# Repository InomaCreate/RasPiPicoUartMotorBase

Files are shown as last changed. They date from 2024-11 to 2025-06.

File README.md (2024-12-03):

# 概要
raspiPICO+KITRONIK-5331を使ったDCモーター制御車両ベースです。  
RasPiPicoUartMotorBase_image4

UART通信を使い、モーター駆動指示、モーター回転数を取得します。
RasPiPicoUartMotorBase_image3

## UART通信仕様
RasPiPicoUartMotorBaseとマイコン等の制御用ボードをUARTで接続し、以下のコマンドをUARTで通知することでDCモーターを駆動させることが可能です。  
また、モーターの回転数（rpm)の情報をUARTで受信することができます。

### UARTコマンド
| UARTコマンド(制御ボード→RasPiPicoUartMotorBase) | 説明 |
|:---|:---:|
|start${"v_r": 右モーター速度指示値, "v_l":左モーター速度指示値} |モーター駆動指示 |  
|emergency_stop|モーター停止 |

※速度指示値は0〜100 ※終端に改行コードCRLF(\r\n)を入れること

| UART応答(制御ボード←RasPiPicoUartMotorBase) | 説明 |
|:---|:---:|
|{"rpm_l":左モーター回転数(rpm),"rpm_r":右モーター回転数(rpm)} |モーター回転数応答 |  

## 準備
### 必要なもの
- Raspberry Pi Pico
- Raspberry Pi Pico用Kitronikモータードライバーボード(KITRONIK-5331)
- エンコーダ付きDCモーター×2個
  - 動作実績：DC 12v モーター エンコーダ付き ギアモーター マウントブラケット付き 65mm(130rpm)
- モーター駆動用バッテリ(モーター電圧に応じて準備）
  
### ソフトウェア
※Raspberry Pi Pico開発環境はThonnyを使用
https://thonny.org/

1. Micro Pythonのファームウェアをセットアップしてください。  
以下サイト参照。  
https://www.marutsu.co.jp/pc/static/large_order/zep/m-z-picoled-da1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  

3. Kitronik用のドライバー(PicoMotorDriver.py)をRaspberry Pi Picoに保存します。    
以下参照。  
https://github.com/KitronikLtd/Kitronik-Pico-Motor-Driver-Board-MicroPython

4. RasPiPicoSource内にあるmain.pyをRaspberry Pi Picoに保存します。  
https://github.com/InomaCreate/RasPiPicoUartMotorBase/blob/main/RasPiPicoSource/main.py

### ハードウェア
1. raspiPICO+KITRONIK-5331を接続し、UART用線を出します。（要ハンダ付け）  
UART1 TX:GPIO4(PIN6), UART1 RX:GPIO5(PIN7), GND(PIN8)から線を出します。  

2. 以下のようにDCモーターと接続します。  
RasPiPicoUartMotorBase_image2new

実際の配線写真↓  
RasPiPicoUartMotorBase_image1

## サンプルプログラム
### 動作実績：
- Raspberry Pi 5（Ubuntu24.04)  
以下、Raspberry Pi 5（Ubuntu24.04)を使ったサンプルプログラムのセットアップ、実行方法を記載します。  

### セットアップ：
1. Raspberry Pi5のUART通信を有効にする  
   1-1. /boot/firmware/config.txtを編集し、以下を追加します。  
   ```enable_uart=1```  
   ```dtoverlay=uart0```  

   1-2. Raspberry Pi5を再起動します  
   ```sudo reboot```
    
   1-3. 再起動後、以下コマンドでuartが有効になっているか確認します。  
   ```sudo dmesg | grep ttyAMA```  
   ttyAMA0が有効になっている場合、以下のピンがUART信号のピンです。  
   ttyAMA0・・・PIN8：GPIO14（TxD）/ PIN10：GPIO15(RxD)  

   1-4. RasPiPicoUartMotorBaseのUART線をRaspberry Pi5のUARTピンと接続します。
   ![RasPiPicoUartMotorBase_image5](https://github.com/user-attachments/assets/a5f7ab8e-4351-4c18-8c67-189dea765469)

3. Raspberry Pi5に必要なパッケージのインストール  
以下のコマンドで、サンプルプログラムを実行するために必要なパッケージをインストールします  
```sudo apt update```  
```sudo apt install libncurses5-dev libncursesw5-dev```  
```pip3 install pyserial```  

### 実行方法：
セットアップしたRaspberry Piでサンプルプログラムを動かします。  
#### モーター駆動用サンプルプログラム
以下スクリプトを実行すると、モーター駆動用のサンプルプログラムが起動します。  
キーを通知すると、前進、後進、モーター速度変更などを行います。（以下表参照）  
```python3 sample_motor_send.py```  

| キー | 動作 |
|:---|:---:|
| i | 前進 |
| k | 後進 |
| s | 右モーター速度UP(+5) |
| a | 左モーター速度UP(+5) |
| x | 右モーター速度DOWN(-5) |
| z | 左モーター速度DOWN(-5) |
| e | モーター停止 |
| q | プログラム終了 |

#### モーター回転数受信サンプルプログラム
以下スクリプトを実行すると、モーター回転数受信のサンプルプログラムが起動します。  
```python3 sample_rcv_rpm.py``` 

## 3Dデータ
3Dデータ(stlファイル）もGitHubにUPしました。必要に応じて3Dプリンターで印刷してご使用ください。  
[https://github.com/InomaCreate/RasPiPicoUartMotorBase/tree/main/3D-data](https://github.com/InomaCreate/RasPiPicoUartMotorBase/blob/main/3D-data/RasPiPicoUartMotorBase_body-Body.stl)

以下のように、Raspberry Pi Picoや電池ボックス、モーター、キャスターを取り付けれるようにしております。
![github_image-06](https://github.com/user-attachments/assets/e641a84a-373e-4542-b344-a977cca06a89)
キャスターは、ホームセンターで買った直径38mmのものです。  
![github_image-07](https://github.com/user-attachments/assets/fa3f5e5d-8827-4ea0-8a7e-6b4a5467271e)

モーターのマウントは、「DC 12v モーター エンコーダ付き ギアモーター マウントブラケット付き 65mm(130rpm)」に付属されていたマウントブランケットをそのまま使用しています。  
![github_image-08](https://github.com/user-attachments/assets/a013b6a9-5359-4d2f-8b34-fa3b3e6589ed)

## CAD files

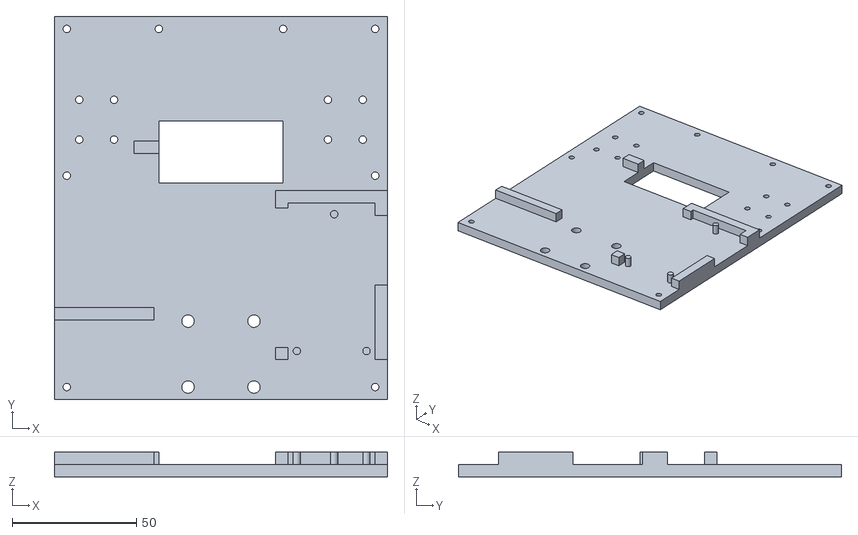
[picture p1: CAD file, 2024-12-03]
3D-data/RasPiPicoUartMotorBase_body-Body.stl
134.0 x 154.0 x 10.0

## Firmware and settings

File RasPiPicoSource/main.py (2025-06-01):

from machine import Pin, I2C, UART
import time
import json
import PicoMotorDriver


import utime
import math
import _thread
import uasyncio as asyncio

#GP２５のLEDを出力ピンとして設定 
led = machine.Pin(25, machine.Pin.OUT)

#出力ピンのスイッチをオン（１）
led.value(1)
 
#指定の秒数待機（５）
utime.sleep(5)
 
#出力ピンのスイッチをオフ（０）
led.value(0)

#GPIOピン番号(左モーター)
LEFT_ENC_A = 0
LEFT_ENC_B = 1

#GPIOピン番号(右モーター)
RIGHT_ENC_A = 27
RIGHT_ENC_B = 26

# 変数の初期化
prev_data=[0,0]
gear_ratio = 46.8 # 使用モーター JGA25-371(12v130RPM)
ppr = 11 # 使用モーター JGA25-371(12v130RPM)
delta=2*math.pi/(4*ppr*gear_ratio)
counter=[0,0]
prev_counter=[0,0]
angle = [0,0]
prev_angle = [0,0]
prev_time = 0 #time.time()
prev_phi = [0,0]
velocity = [0,0]
rpm = [0,0]

left_enc_a = machine.Pin(LEFT_ENC_A, machine.Pin.IN, machine.Pin.PULL_UP)
left_enc_b = machine.Pin(LEFT_ENC_B, machine.Pin.IN, machine.Pin.PULL_UP)

right_enc_a = machine.Pin(RIGHT_ENC_A, machine.Pin.IN, machine.Pin.PULL_UP)
right_enc_b = machine.Pin(RIGHT_ENC_B, machine.Pin.IN, machine.Pin.PULL_UP)


# 左モーター　パルスカウント計算
def callback(channel):
    global prev_data,counter,angle,left_enc_a,left_enc_b
    
    current_a = left_enc_a.value()
    current_b = left_enc_b.value()

    encoded = (current_a<<1)|current_b
    sum=(prev_data[0]<<2)|encoded

    #print(bin(sum))
    if (sum==0b0010 or sum==0b1011 or sum==0b1101 or sum==0b0100):
        counter[0] -= 1
        angle[0]-=delta
    elif (sum==0b0001 or sum==0b0111 or sum==0b1110 or sum==0b1000):
        counter[0] += 1
        angle[0]+=delta

    prev_data[0]=encoded


# 右モーター　パルスカウント計算
def callback2(channel):
    global prev_data,counter,angle,right_enc_a,right_enc_b
    
    current_a = right_enc_a.value()
    current_b = right_enc_b.value()

    encoded = (current_a<<1)|current_b
    sum=(prev_data[1]<<2)|encoded

    # print(bin(sum)) 左と判定が逆になるはず
    if (sum==0b0010 or sum==0b1011 or sum==0b1101 or sum==0b0100):
        counter[1] += 1
        angle[1]+=delta
    elif (sum==0b0001 or sum==0b0111 or sum==0b1110 or sum==0b1000):
        counter[1] -= 1
        angle[1]-=delta

    prev_data[1]=encoded
    
    
# カウンター値から速度算出
def calc_velocity():
    global counter, prev_counter, prev_phi, prev_time,angle,prev_angle,dt
    # print("angle="+str(angle))

    now=time.time()
    dt = now - prev_time
    # print("dt="+str(dt))
    print("prev_counter[0]="+str(prev_counter[0]))
    print("now="+str(now))
    print("prev_time"+str(prev_time))
    print("dt="+str(dt))
    if dt == 0:
        print("dt is zero")
    else:        
        for i in range(2):    
            if counter[i] != prev_counter[i]:
                phi = counter[i]*delta
                velocity[i] = (phi - prev_phi[i])/dt
                print("velocity["+str(i)+"]="+str(velocity[i]))
                rpm[i] = velocity[i]*60/(2*math.pi)
                print("rpm["+str(i)+"]="+str(rpm[i])) # for debug
                prev_counter[i] = counter[i]
                prev_phi[i] = phi
                prev_angle[i] = angle[i]
            else:
                velocity[i] = 0
                rpm[i] = 0        
        prev_time = now

async def rpm_send():
    print("rpm_send start!!")
    uart = UART(1,115200)
    while True:
        calc_velocity()
        #uartで応答（回転数）
        json_string = json.dumps({"rpm_l":rpm[0],"rpm_r":rpm[1]})
        print(json_string)
        uart.write(json_string.encode('utf-8'))
        uart.write("\r\n".encode())
        await asyncio.sleep(1)

async def uart_rcv():
    print("uart_rcv start!!")
    uart = UART(1,115200)
    send_counter = 0
    while True:        
        buf = bytearray()
        data_flg = False
        while True:
            char = uart.read(1)
            #print(char)
            if char is None:
                break
            #print(char)
            buf.extend(char)
            if char == b'\n':
                data_flg = True
                break
            # time.sleep(0.001)
            await asyncio.sleep(0.001)

        if data_flg == True:
            byte_data = buf
            data_flg = False
        else:
            await asyncio.sleep(0.001)
            continue        
                
        if byte_data is not None:
            led.value(0) # for debug
            if 'start' in byte_data:
                print("yes start")
                
            elif 'emergency_stop' in byte_data:
                print("emergency_stop")
                board.motorOff(1)
                board.motorOff(2)
                #led.value(0) # for debug
                continue
            else:
                #led.value(0) # for debug
                continue
             
            #led.value(0) # for debug
            
            str_data = byte_data.decode('utf-8').split('$')[1]
            if len(str_data) != 0:
                try:
                    json_data = json.loads(str_data)
                except ValueError as e:
                    print("JSON Error!!")
                    continue

                v_r = json_data["v_r"]
                v_l = json_data["v_l"]

                # add uart --->
                if v_r > 0 and v_l > 0:
    #                 print("forward!!")
                    board.motorOn(1, 'f', abs(v_r))
                    board.motorOn(2, 'f', abs(v_l))

                elif v_r > 0 and v_l < 0:
    #                 print("right!!")
                    board.motorOn(1, 'f', abs(v_r))
                    board.motorOn(2, 'r', abs(v_l))

                elif v_r < 0 and v_l > 0:
#                 print("left!!")
                    board.motorOn(1, 'r', abs(v_r))
                    board.motorOn(2, 'f', abs(v_l))

                elif v_r < 0 and v_l < 0:
#                 print("back!!")
                    board.motorOn(1, 'r', abs(v_r))
                    board.motorOn(2, 'r', abs(v_l))

                else:
                    #led.value(0) # for debug
                    board.motorOff(1)
                    board.motorOff(2)
            else:
                #led.value(0) # for debug
                board.motorOff(1)
                board.motorOff(2)



# 割り込みイベントの設定
left_enc_a.irq(trigger=Pin.IRQ_RISING | Pin.IRQ_FALLING,  handler=callback)
left_enc_b.irq(trigger=Pin.IRQ_RISING | Pin.IRQ_FALLING,  handler=callback)

right_enc_a.irq(trigger=Pin.IRQ_RISING | Pin.IRQ_FALLING,  handler=callback2)
right_enc_b.irq(trigger=Pin.IRQ_RISING | Pin.IRQ_FALLING,  handler=callback2)


async def main():
    await asyncio.gather(uart_rcv(),rpm_send())


if __name__ == "__main__":
     board = PicoMotorDriver.KitronikPicoMotor()
     asyncio.run(main())

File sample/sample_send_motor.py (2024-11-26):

import curses
import json
import serial

class SendMotor:
    def __init__(self):
        self.ser = serial.Serial('/dev/ttyAMA0', 115200, timeout=1)  # Initialize UART
        self.r_speed = 80
        self.l_speed = 80
    
    def key_detect(self, stdscr):
        # Cursesのセットアップ
        stdscr.nodelay(True)  # 非ブロッキングモードを設定
        stdscr.clear()
        stdscr.addstr(0, 0, "キーを押してください（'q'で終了）")
        stdscr.addstr(1, 0, "i:前進, k:後進")
        stdscr.addstr(2, 0, "e:モーター停止")
        stdscr.addstr(3, 0, "a:speed up left, b:speed up right")
        stdscr.addstr(4, 0, "z:speed down left, x:speed down right")

        while True:
            key = stdscr.getch()  # キー入力を取得
            if key != -1:  # キーが押されている場合
                if key == ord('q'):  # 'q'キーの場合
                    self.clear_line(stdscr, 5)  # 5行目をクリア
                    stdscr.addstr(5, 0, "終了します")
                    stdscr.refresh()
                    self.ser.close()
                    break

                elif key == ord('i'):
                    json_string = "start$" + json.dumps({"v_r": self.r_speed, "v_l": self.l_speed})
                    self.clear_line(stdscr, 5)  # 5行目をクリア
                    stdscr.addstr(5, 0, f"motor send!!: {json_string}")
                    self.ser.write(json_string.encode('utf-8'))
                    self.ser.write(b'\r\n')

                elif key == ord('k'):
                    json_string = "start$" + json.dumps({"v_r": -1*self.r_speed, "v_l": -1*self.l_speed})
                    self.clear_line(stdscr, 5)  # 5行目をクリア
                    stdscr.addstr(5, 0, f"motor send!!: {json_string}")
                    self.ser.write(json_string.encode('utf-8'))
                    self.ser.write(b'\r\n')

                elif key == ord('s'):
                    self.r_speed = self.r_speed + 5
                    if self.r_speed > 100:
                        self.r_speed = 100
                    self.clear_line(stdscr, 5)  # 5行目をクリア
                    stdscr.addstr(5, 0, f"right motor speed set: {self.r_speed}")

                elif key == ord('x'):
                    self.r_speed = self.r_speed - 5
                    if self.r_speed < 0:
                        self.r_speed = 0
                    self.clear_line(stdscr, 5)  # 5行目をクリア
                    stdscr.addstr(5, 0, f"right motor speed set: {self.r_speed}")

                elif key == ord('a'):
                    self.l_speed = self.l_speed + 5
                    if self.l_speed > 100:
                        self.l_speed = 100
                    self.clear_line(stdscr, 5)  # 5行目をクリア
                    stdscr.addstr(5, 0, f"left motor speed set: {self.l_speed}")

                elif key == ord('z'):
                    self.l_speed = self.l_speed - 5
                    if self.l_speed < 0:
                        self.l_speed = 0
                    self.clear_line(stdscr, 5)  # 5行目をクリア
                    stdscr.addstr(5, 0, f"left motor speed set: {self.l_speed}")

                elif key == ord('e'):
                    self.clear_line(stdscr, 5)  # 5行目をクリア
                    stdscr.addstr(5, 0, f"emergency stop")
                    self.ser.write(b'emergency_stop\r\n')


                else:
                    self.clear_line(stdscr, 5)  # 5行目をクリア
                    stdscr.addstr(5, 0, f"キーコード: {key}")

                stdscr.refresh()

    def clear_line(self, stdscr, row):
        max_y, max_x = stdscr.getmaxyx()
        stdscr.addstr(row, 0, " " * (max_x - 1))  # 空白文字で上書き
        stdscr.refresh()

def main(stdscr):
    # Cursesのセットアップ
    motor = SendMotor()
    motor.key_detect(stdscr)  # stdscrを渡してkey_detectを実行


if __name__ == '__main__':
    # Cursesのラッパーを使用して実行
    curses.wrapper(main)

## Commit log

2024-11-26 サンプルプログラム追加
2024-11-26 回転数通知 定期的に通知されるように修正
2024-12-03 3dデータ stlファイル追加
    [RasPiPicoUartMotorBase_body-Body.stl]
2025-05-29 ギヤ比見直し →ギア比1:50 →PPR:11 に変更
2025-06-01 モーターJGA25-371(12v130RPM)ギア比、PPR設定
